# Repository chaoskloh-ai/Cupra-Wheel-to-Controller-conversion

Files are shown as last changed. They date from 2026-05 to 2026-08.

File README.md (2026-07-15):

# Cupra Steering Wheel Gamepad 🎮

I was inspired by Funny_Procedure_7609 on Reddit's conversion of a Porsche Steering Wheel and decided that I can't be that hard to make all to Buttons work. One Month later I have a working Steering Wheel with all Buttons converted on an ESP32 working over Bluetooth. I am using the BLE Libary for Ardunino for connecting to Windows. If you buy an Arduino ESP32-S3 or some other board that has HID communication directly integrated you can also use a wired connection. Currently I am working on finalzing everything and fitting it.

Huge thanks to the Community over at [vwidtalk.com](https://www.vwidtalk.com/threads/i-have-real-steering-wheel-buttons.18466/page-8) and specifically JohnnyForElectric who posted his ID 4 LIN communication snippets. With out this file the Project would have taken way longer.

Steering Wheel Example

## Features

*   **Steering Wheel Integration**
    *   Reads button states from Volkswagen steering wheels with LIN bus communication, including models from VW, Audi, Skoda, and Seat (tested with a Cupra Formentor/Leon steering wheel, compatibility with other VAG models is very likely but not guaranteed).
    *   All Buttons work!
*   **Bluetooth Capabilities**
    *   Transmits button presses wirelessly as a standard Bluetooth gamepad, compatible with PCs and other Bluetooth-enabled devices.
    *   Utilizes Bluetooth Low Energy (BLE) for efficient power consumption.
*   **Backlight Control**
    *   Provides 128 levels of brightness control for the steering wheel buttons' backlight.

## How It Works

This project utilizes the LIN bus, a communication network in vehicles, to read button presses from the steering wheel. The ESP32 microcontroller acts as the master node on the LIN bus, requesting and receiving data from the steering wheel (the slave node).

1.  **Button Press:** When you press a button on the steering wheel, the steering wheel module sends a data packet over the LIN bus.
2.  **ESP32 Reads Data:** The ESP32, connected to the LIN bus via the LIN transceiver, receives and decodes this data packet.
3.  **BLE Transmission:** The ESP32 translates the button press into a standard gamepad event and transmits it over BLE.
4.  **Game Action:** The receiving device (e.g., PC) recognizes the gamepad event and triggers the corresponding action in the game or application.

## Parts Used

| Part | Description | Part Number |
|---|---|---|
| Steering Wheel | Top Spec Cupra Steering Wheel | 5FA 419 091 FK XEY |
| LIN Transceiver | TJA1020, TJA1021, or SIT1021T (I used a cheap TJA1021T from Aliexpress | - |
| ESP32 | Any ESP32 development board | - |
| 5V-12V Step-Up-Module | Any 5V-12V will do if you plan on using USB-C | - |
| Tanleki Tiny Emulator | For Fanatec at least you will need an Emulator for the force Feedback to work| [I used this one](https://de.aliexpress.com/item/1005007286369952.html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)|
| Fanatec QR1 Wheelside | Because I am using Fanatec your Wheelside may wary | - |
| Steering Column | I used a steering column of a Steat Leon. Not sure if they are all the same  | 5WB 419 502 F |
| Center Wheel Screw | Center Screw since I am using OEM Parts to attach the Wheel | N90799102 |

## Buidling the Adapter

Please note that depending on your specific needs or constraints you may need to do things differently.

I went the OEM route because I think is cheaper than manufacturing everything from scratch. For the first step I cut the front most part of the steering wheel a bit behind the spline. Then I welded the piece to a steel plate. You have to make sure everything stays relativly lined up or your wheel will later be wobbly. 
On the backside opposite the column part I attached the wheelside adapter.

Adapter Example 1
Adapter Example 2

## Wiring Diagram

Please note that the wiring diagram is based on my specific setup. The wiring may be different depending on the steering wheel model or MCU board used.

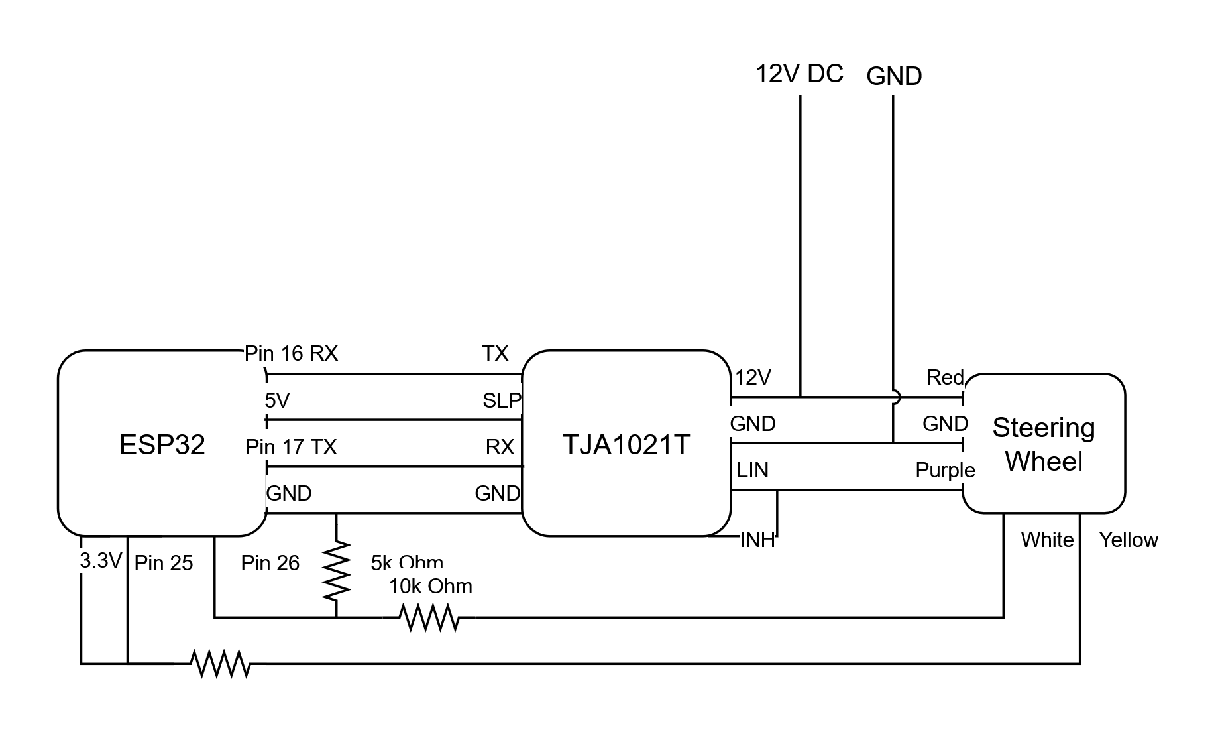
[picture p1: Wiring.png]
Wiring Diagram


## LIN Protocol

The Steering Wheel communicates over LIN at BAUD 19200 with 8 Databits and 1 Stopbit. Sync is typical 0x55 at 755 µs (LOW) with 112 µs (HIGH) Sync Delimiter.

The Bytes in this Table are all Databytes and the size is the Databyte size.

| Frame ID | Type | Description | Size | Byte 0 | Byte 1 | Byte 2 | Byte 3 | Byte 6 |
|---|---|---|---|---|---|---|---|---|
| 0x0D | Master Request | Set backlight level | 2 | 0x0 - 0x7F - Brightness level | 0x9F - Enables/disables button state responses | - | - | - |
| 0x0E | Slave Response | Button states Left Island & Paddles  | 8 | Increases on every response | - | Left button pressed (see mapping below) | Left thumbwheel scroll direction | Shift paddles (see mapping below) |
| 0x0F | Slave Response | Button states Right Island | 8 | Increases on every response | - | Right button pressed (see mapping below) | - | - |
| 0x0C | Master Response  | diagnostics data | 4 | Increases on every response | - | - | - | - |
| 0x3A | Slave Response | diagnostics data | 2 | Increases on every response | - | - | - | - |

**Button Mapping**

The Ignition and Cruise Control are physical wires.

| Wire color | Information | Button |
|---|---|---|
| yellow | ~ 200 Ohm when pressed | Ignition |
| white | 12V! drops to 0V when pressed | Cruise Control |

| Frame ID + Byte | Hex  | Button |
|---|---|---|
| 0x0E  Byte 2 | 0x12 | vol + |
| 0x0E  Byte 2 | 0x12 | vol - |
| 0x0E  Byte 2 | 0x20 | mute |
| 0x0E  Byte 2 | 0x07 | ok |
| 0x0E  Byte 2 | 0x06 | up |
| 0x0E  Byte 2 | 0x06 | down |
| 0x0E  Byte 2 | 0x02 | right |
| 0x0E  Byte 2 | 0x03 | left |
| 0x0E  Byte 2 | 0x15 | next |
| 0x0E  Byte 2 | 0x16 | prev |
| 0x0E  Byte 2 | 0x19 | voice |
| 0x0E  Byte 2 | 0x23 | view |
| 0x0E  Byte 2 | 0x25 | heat |
| 0x0E  Byte 2 | 0x70 | cupra |
| 0x0E  Byte 2 | 0x74 | lane assist |
|-----------------|------|-----------------|
| 0x0E  Byte 6 | 0x01 | paddle - |
| 0x0E  Byte 6 | 0x02 | paddle + |
| 0x0E  Byte 6 | 0x03 | both paddles |
|-----------------|------|-----------------|
| 0x0F  Byte 2 | 0x81 | set |
| 0x0F  Byte 2 | 0x82 | + |
| 0x0F  Byte 2 | 0x84 | - |
| 0x0F  Byte 2 | 0x88 | res |
| 0x0F  Byte 2 | 0xB0 | distance |

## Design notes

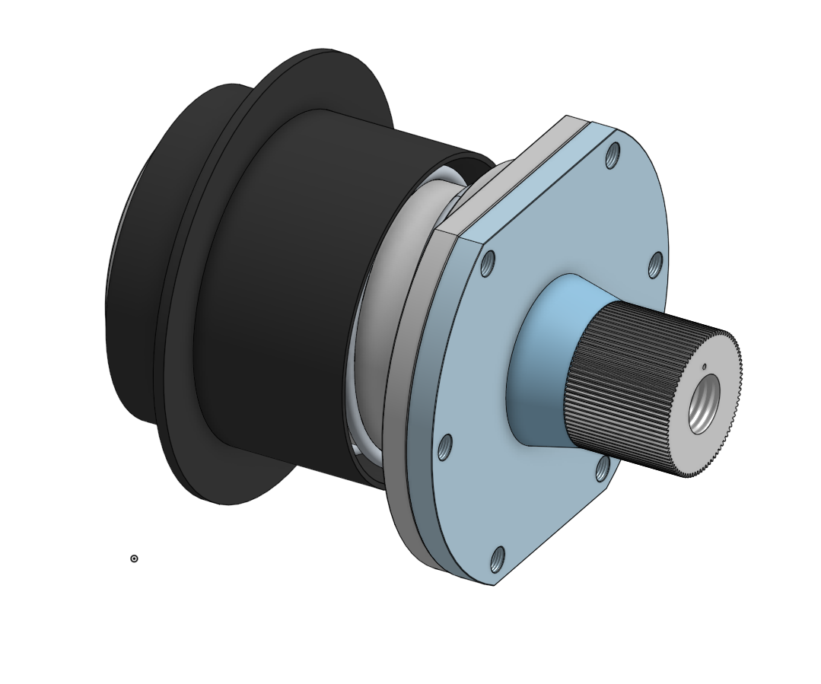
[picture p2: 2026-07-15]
Custom Wheel Adapter.png

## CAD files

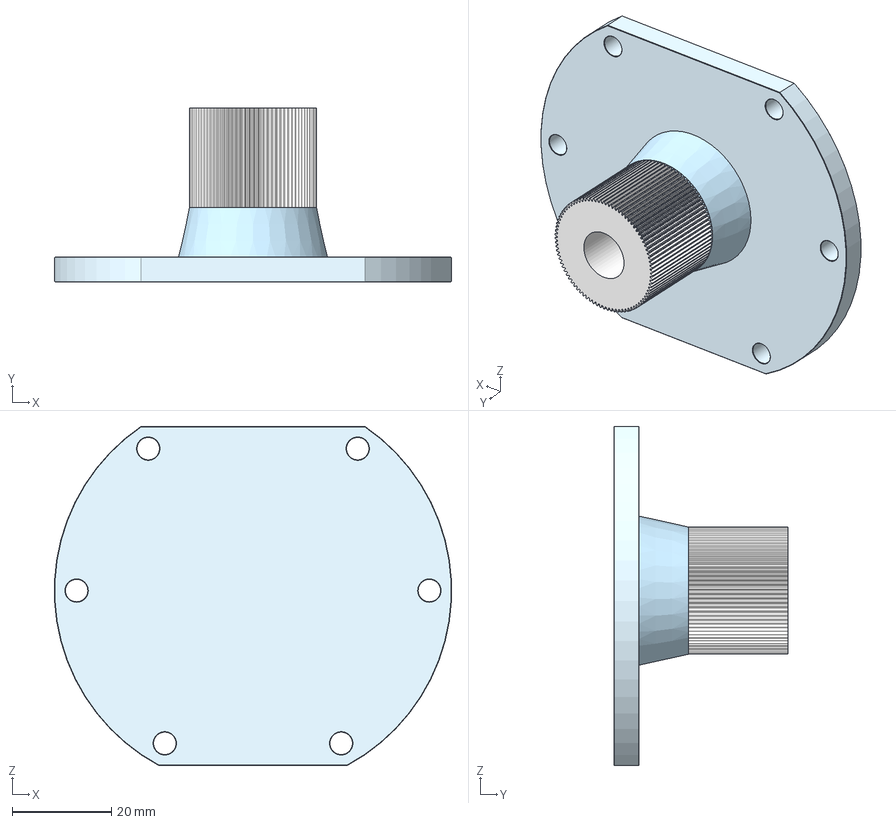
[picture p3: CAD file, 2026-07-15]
Assembly 1.step
79.9 x 35.0 x 68.3 mm
Spur gear (86 teeth)

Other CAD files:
Assembly 1.stl

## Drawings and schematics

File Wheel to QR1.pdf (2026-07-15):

# Ø10,5 THRU M12x1,5 THRU

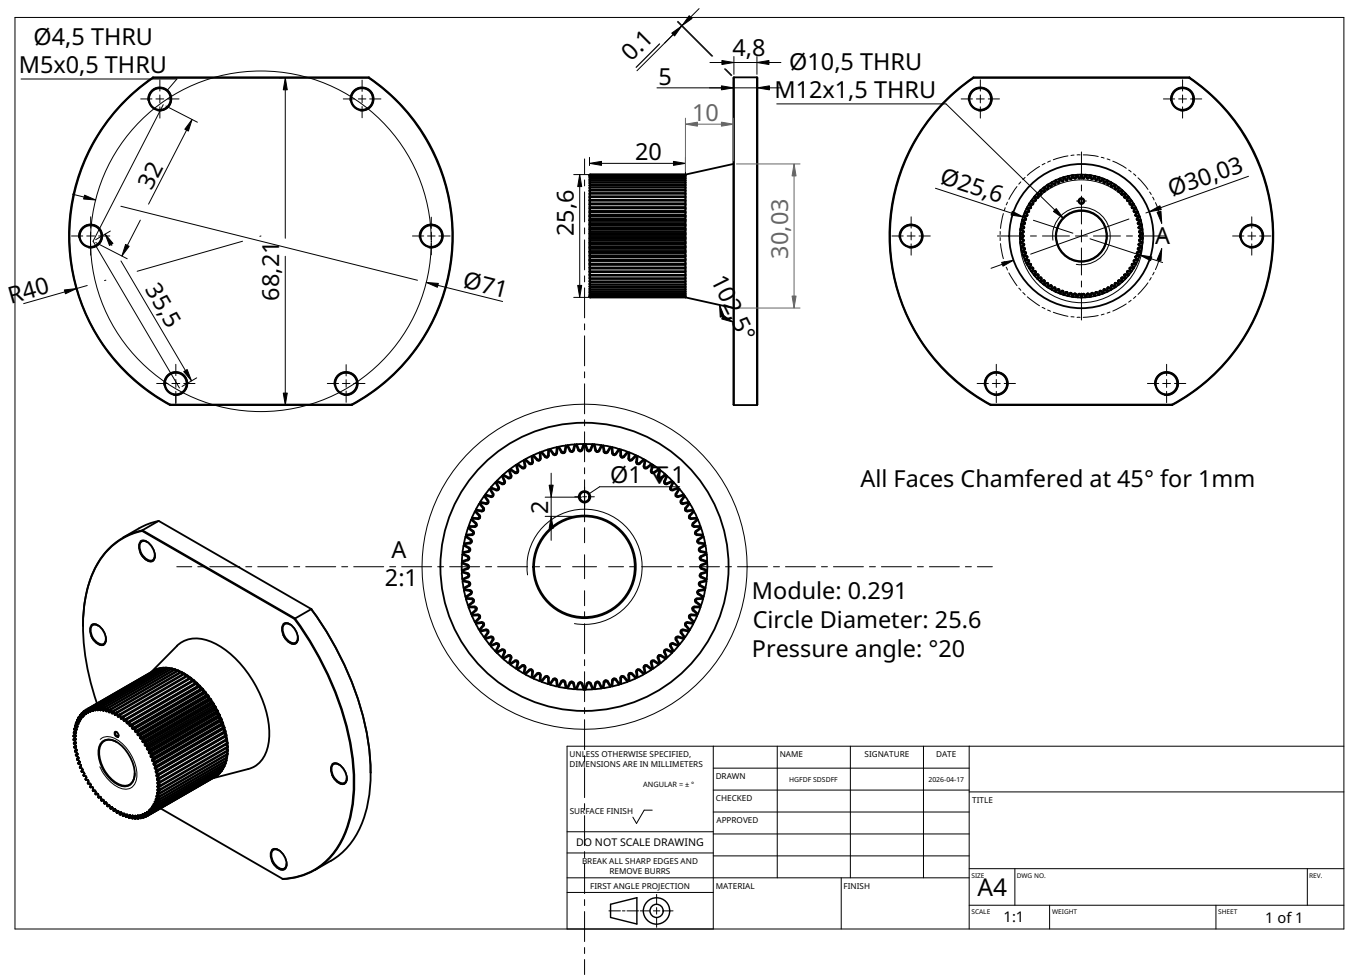
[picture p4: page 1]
ANGULAR = ± °; SURFACE FINISH; NAME; SIGNATURE; DATE; DRAWN; HGFDF SDSDFF; CHECKED; APPROVED; MATERIAL; FINISH; TITLE; SIZE; DWG NO.; REV.; SCALE; WEIGHT; SHEET; Module: 0.291; Circle Diameter: 25.6 Pressure angle: °20; Ø4,5 THRU; M5x0,5 THRU

All Faces Chamfered at 45° for 1mm

UNLESS OTHERWISE SPECIFIED,
DIMENSIONS ARE IN MILLIMETERS

DO NOT SCALE DRAWING
BREAK ALL SHARP EDGES AND
REMOVE BURRS
FIRST ANGLE PROJECTION

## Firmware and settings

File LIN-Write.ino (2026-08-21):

#include <Arduino.h>
#include <BleGamepad.h>

#define LIN_RX 16
#define LIN_TX 17
#define LIN_BAUD 19200
#define PIN_SLP_N 32

#define PIN_ACC_WEISS 25
#define PIN_START_GELB 26

// --- NEU: Debug-Logging für die linke Insel (Scroll-Cluster) ---
// Auf 0 setzen, um das Logging wieder abzuschalten.
#define DEBUG_LIN_CODES 1

#if DEBUG_LIN_CODES
  #define LIN_DEBUG_PRINT(...) Serial.print(__VA_ARGS__)
  #define LIN_DEBUG_PRINTLN(...) Serial.println(__VA_ARGS__)
#else
  #define LIN_DEBUG_PRINT(...)
  #define LIN_DEBUG_PRINTLN(...)
#endif

// --- Entprellung nur noch für die direkten GPIO/ADC-Taster (BTN24/BTN25) ---
// Die LIN-Buttons (Wippen, Scroll-Cluster, restliche Tasten) werden NICHT
// mehr per Zeit-Debounce verzögert - dafür sorgt jetzt die Checksummen-
// Prüfung in pollSlave() dafür, dass nur gültige, unverfälschte Frames
// verarbeitet werden. Das vermeidet die doppelte Latenz, die durch
// Zeit-Debounce bei einer 60ms-Polling-Kadenz entstehen würde.
#define DEBOUNCE_MS_BUTTONS 25
#define DEBOUNCE_MS_START   35

// --- Hysterese-Schwellen für BTN25 (START_GELB) ---
#define START_PRESS_THRESHOLD   3400
#define START_RELEASE_THRESHOLD 3900

BleGamepad bleGamepad("Cupra Wheel", "VAG Retrofit", 100);

unsigned long lastTxTime = 0;
unsigned long lastUdsTime = 0;
uint8_t scheduleStep = 0;

uint8_t lastLeftButton = 0;
uint8_t lastLeftDirection = 0;
uint8_t lastRightButton = 0;
uint8_t lastWippenByte = 0;
bool lastAccState = HIGH;
bool lastStartState = false;

// --- Zwischenspeicher für die Entprellung (nur GPIO/ADC-Taster) ---
bool pendingAccState = HIGH;
unsigned long accChangeTime = 0;

bool pendingStartState = false;
unsigned long startChangeTime = 0;

uint32_t simhubButtons = 0;

void triggerGamepadButton(uint8_t buttonId, bool pressed) {
  if (bleGamepad.isConnected()) {
    if (pressed) bleGamepad.press(buttonId);
    else bleGamepad.release(buttonId);
    bleGamepad.sendReport();
  }

  Serial.print(buttonId);
  Serial.print(":");
  Serial.println(pressed ? 1 : 0);
}

uint8_t calculateLINPID(uint8_t id) {
  uint8_t p0 = ((id >> 0) & 1) ^ ((id >> 1) & 1) ^ ((id >> 2) & 1) ^ ((id >> 4) & 1);
  uint8_t p1 = ~(((id >> 1) & 1) ^ ((id >> 3) & 1) ^ ((id >> 4) & 1) ^ ((id >> 5) & 1)) & 1;
  return id | (p0 << 6) | (p1 << 7);
}

uint8_t checksumEnhanced(uint8_t pid, const uint8_t* data, uint8_t len) {
  uint16_t sum = pid;
  for (uint8_t i = 0; i < len; i++) {
    sum += data[i];
    if (sum >= 256) sum = (sum & 0xFF) + 1;
  }
  return (uint8_t)(~sum);
}

// --- NEU: prüft die vom Slave gesendete Checksumme gegen die berechnete.
// Das ist jetzt der einzige Schutz gegen Störungen/Bitfehler auf dem LIN-Bus -
// ohne künstliche Verzögerung, da nur ungültige Frames verworfen werden. ---
bool verifyLinChecksum(uint8_t pid, const uint8_t* data, uint8_t len, uint8_t receivedChecksum) {
  return checksumEnhanced(pid, data, len) == receivedChecksum;
}

void generatePhysicalHeader() {
  Serial1.end();
  pinMode(LIN_TX, OUTPUT);
  digitalWrite(LIN_TX, LOW);
  delayMicroseconds(755);
  digitalWrite(LIN_TX, HIGH);
  delayMicroseconds(112);
  Serial1.begin(LIN_BAUD, SERIAL_8N1, LIN_RX, LIN_TX);
}

void sendUdsInitialization() {
  uint8_t pid = calculateLINPID(0x3C);
  uint8_t payload[8] = { 0x01, 0x02, 0x10, 0x03, 0xFF, 0xFF, 0xFF, 0xFF };
  uint8_t checksum = 0xF9;

  generatePhysicalHeader();
  Serial1.write(0x55);
  Serial1.write(pid);
  for (uint8_t i = 0; i < 8; i++) Serial1.write(payload[i]);
  Serial1.write(checksum);
  Serial1.flush();
}

// --- Linke Insel: direkt/sofort, keine künstliche Verzögerung.
// Schutz vor Störungen läuft jetzt komplett über die Checksummen-Prüfung
// in pollSlave() - dadurch reagieren alle Tasten (normale Tasten, Wippen,
// Scroll-Cluster) wieder mit der ursprünglichen ~60ms Poll-Latenz. ---
void interpretLeftIsland(uint8_t b1, uint8_t b3, uint8_t b6) {
  // Pfeiltasten (b1=0x06): b3 kodiert die Richtung. Gemessen: hoch=0x01,
  // runter=0x0F. Beim schnellen Scrollen tauchen dazwischen kurz andere,
  // ungültige b3-Werte auf, die vorher per Ternary (alles außer 0x01 =
  // "runter") fälschlich als "runter" gewertet wurden - das war der Grund,
  // warum nur "hoch" gelegentlich in die falsche Richtung sprang. Jetzt
  // werden nur die zwei bestätigten Codes akzeptiert, alles andere wird als
  // Störwert ignoriert und der zuletzt bestätigte Zustand bleibt bestehen.
  if (b1 == 0x06 && b3 != 0x01 && b3 != 0x0F) {
    return;
  }

  if (b1 != lastLeftButton || b3 != lastLeftDirection) {
    if (lastLeftButton != 0x00) {
      if (lastLeftButton == 0x12) {
        triggerGamepadButton(1, false);
        triggerGamepadButton(2, false);
      } else if (lastLeftButton == 0x06) {
        triggerGamepadButton(6, false);
        triggerGamepadButton(7, false);
      } else {
        switch (lastLeftButton) {
          case 0x20: triggerGamepadButton(3, false); break;
          case 0x07: triggerGamepadButton(4, false); break;
          case 0x03: triggerGamepadButton(8, false); break;
          case 0x02: triggerGamepadButton(9, false); break;
          case 0x15: triggerGamepadButton(10, false); break;
          case 0x16: triggerGamepadButton(11, false); break;
          case 0x19: triggerGamepadButton(12, false); break;
          case 0x23: triggerGamepadButton(13, false); break;
          case 0x25: triggerGamepadButton(14, false); break;
          case 0x70: triggerGamepadButton(15, false); break;
          case 0x74: triggerGamepadButton(16, false); break;
        }
      }
    }

    lastLeftButton = b1;
    lastLeftDirection = b3;

    if (b1 != 0x00) {
      switch (b1) {
        case 0x12: triggerGamepadButton((b3 == 0x01) ? 1 : 2, true); break;
        case 0x20: triggerGamepadButton(3, true); break;
        case 0x07: triggerGamepadButton(4, true); break;
        case 0x06: triggerGamepadButton((b3 == 0x01) ? 6 : 7, true); break;
        case 0x03: triggerGamepadButton(8, true); break;
        case 0x02: triggerGamepadButton(9, true); break;
        case 0x15: triggerGamepadButton(10, true); break;
        case 0x16: triggerGamepadButton(11, true); break;
        case 0x19: triggerGamepadButton(12, true); break;
        case 0x23: triggerGamepadButton(13, true); break;
        case 0x25: triggerGamepadButton(14, true); break;
        case 0x70: triggerGamepadButton(15, true); break;
        case 0x74: triggerGamepadButton(16, true); break;
      }
    }
  }

  if (b6 != lastWippenByte) {
    lastWippenByte = b6;
    triggerGamepadButton(17, false);
    triggerGamepadButton(18, false);

    switch (b6) {
      case 0x01: triggerGamepadButton(17, true); break;
      case 0x02: triggerGamepadButton(18, true); break;
      case 0x03:
        triggerGamepadButton(17, true);
        triggerGamepadButton(18, true);
        break;
    }
  }
}

void interpretRightIsland(uint8_t b2) {
  if (b2 == lastRightButton) return;

  switch (lastRightButton) {
    case 0x81: triggerGamepadButton(19, false); break;
    case 0x82: triggerGamepadButton(20, false); break;
    case 0x84: triggerGamepadButton(21, false); break;
    case 0x88: triggerGamepadButton(22, false); break;
    case 0xB0: triggerGamepadButton(23, false); break;
  }

  lastRightButton = b2;

  if (b2 != 0x80) {
    switch (b2) {
      case 0x81: triggerGamepadButton(19, true); break;
      case 0x82: triggerGamepadButton(20, true); break;
      case 0x84: triggerGamepadButton(21, true); break;
      case 0x88: triggerGamepadButton(22, true); break;
      case 0xB0: triggerGamepadButton(23, true); break;
    }
  }
}

void pollSlave(uint8_t id) {
  uint8_t pid = calculateLINPID(id);
  generatePhysicalHeader();

  Serial1.write(0x55);
  Serial1.write(pid);
  Serial1.flush();

  uint8_t rawBuffer[15];
  uint8_t idx = 0;

  unsigned long startTime = micros();
  while ((micros() - startTime < 6000) && (idx < 11)) {
    if (Serial1.available()) {
      rawBuffer[idx++] = Serial1.read();
    }
  }

  if (idx >= 10) {
    // Checksumme prüfen, BEVOR der Frame verwertet wird. Ein durch Störung
    // verfälschtes Byte (z.B. ein falscher Scroll-Code) fällt hier raus und
    // der zuletzt bestätigte Zustand bleibt unverändert bestehen - ohne
    // jede zusätzliche Latenz für gültige Frames.
    uint8_t dataLen = idx - 3; // abzüglich 0x55, PID, Checksumme
    bool checksumOk = verifyLinChecksum(rawBuffer[1], &rawBuffer[2], dataLen, rawBuffer[idx - 1]);

    if (checksumOk) {
      if (id == 0x0E) {
        interpretLeftIsland(rawBuffer[3], rawBuffer[5], rawBuffer[8]);
      } else if (id == 0x0F) {
        interpretRightIsland(rawBuffer[4]);
      }
    }
  }
}

void sendBacklight() {
  uint8_t pid = calculateLINPID(0x0D);
  uint8_t payload[4] = { 0x7F, 0xF9, 0xFF, 0xFF };
  uint8_t checksum = checksumEnhanced(pid, payload, 4);

  generatePhysicalHeader();
  Serial1.write(0x55);
  Serial1.write(pid);
  for (uint8_t i = 0; i < 4; i++) Serial1.write(payload[i]);
  Serial1.write(checksum);
  Serial1.flush();
  delay(2);
}

// --- mehrere ADC-Samples mitteln, um einzelne Ausreißer zu glätten ---
int readStartAdcAveraged() {
  const uint8_t samples = 4;
  uint32_t sum = 0;
  for (uint8_t i = 0; i < samples; i++) {
    sum += analogRead(PIN_START_GELB);
  }
  return sum / samples;
}

void checkAnalogButtons() {
  unsigned long now = millis();

  // --- BTN24 (ACC_WEISS) - entprellt ---
  bool rawAcc = digitalRead(PIN_ACC_WEISS);
  if (rawAcc != pendingAccState) {
    pendingAccState = rawAcc;
    accChangeTime = now;
  }
  if ((now - accChangeTime) >= DEBOUNCE_MS_BUTTONS && pendingAccState != lastAccState) {
    lastAccState = pendingAccState;
    triggerGamepadButton(24, (lastAccState == LOW));
  }

  // --- BTN25 (START_GELB) - Mittelwert + Hysterese + Entprellung ---
  int adcGelb = readStartAdcAveraged();
  bool rawStart = lastStartState
      ? (adcGelb < START_RELEASE_THRESHOLD)
      : (adcGelb < START_PRESS_THRESHOLD);

  if (rawStart != pendingStartState) {
    pendingStartState = rawStart;
    startChangeTime = now;
  }
  if ((now - startChangeTime) >= DEBOUNCE_MS_START && pendingStartState != lastStartState) {
    lastStartState = pendingStartState;
    triggerGamepadButton(25, lastStartState);
  }
}

void setup() {
  Serial.begin(115200);

  pinMode(PIN_ACC_WEISS, INPUT);
  pinMode(PIN_START_GELB, INPUT_PULLUP);

  pinMode(PIN_SLP_N, OUTPUT);
  digitalWrite(PIN_SLP_N, HIGH);
  delay(5);

  BleGamepadConfiguration bleGamepadConfig;
  bleGamepadConfig.setAutoReport(false);
  bleGamepadConfig.setButtonCount(32);

  bleGamepad.begin(&bleGamepadConfig);
}

void loop() {
  unsigned long currentMillis = millis();

  if (currentMillis - lastUdsTime >= 1000) {
    lastUdsTime = currentMillis;
    sendUdsInitialization();
  }

  if (currentMillis - lastTxTime >= 20) {
    lastTxTime = currentMillis;

    switch (scheduleStep) {
      case 0: sendBacklight(); break;
      case 1: pollSlave(0x0E); break;
      case 2: pollSlave(0x0F); break;
    }
    scheduleStep = (scheduleStep + 1) % 3;
  }

  checkAnalogButtons();

  // INTERNER SIMHUB-STANDARD:
  if (Serial.available() > 0) {
    char cmd = Serial.read();
    if (cmd == '2') {
      Serial.write(0x03);
      Serial.write((uint8_t)(simhubButtons & 0xFF));
      Serial.write((uint8_t)((simhubButtons >> 8) & 0xFF));
      Serial.write((uint8_t)((simhubButtons >> 16) & 0xFF));
      Serial.write((uint8_t)((simhubButtons >> 24) & 0xFF));
    }
  }
}

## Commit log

2026-05-22 Revise README for Cupra Steering Wheel project
    Updated project description, features, and LIN protocol details in README.
2026-05-22 Rename Steering Wheel.jpg to SteeringWheel.jpg
2026-07-15 Rename Sample Image 2.jpg to SampleImage2.jpg
2026-07-15 Rename Sample Image 1.jpg to SampleImage1.jpg
2026-08-13 Update LIN-Write.ino
    Added holding down functionallity
    fixed accidental Button presses
    [LIN-Write.ino]
2026-08-21 Enhance button debounce and add debug logging
    Added debug logging and improved debounce handling for buttons.
